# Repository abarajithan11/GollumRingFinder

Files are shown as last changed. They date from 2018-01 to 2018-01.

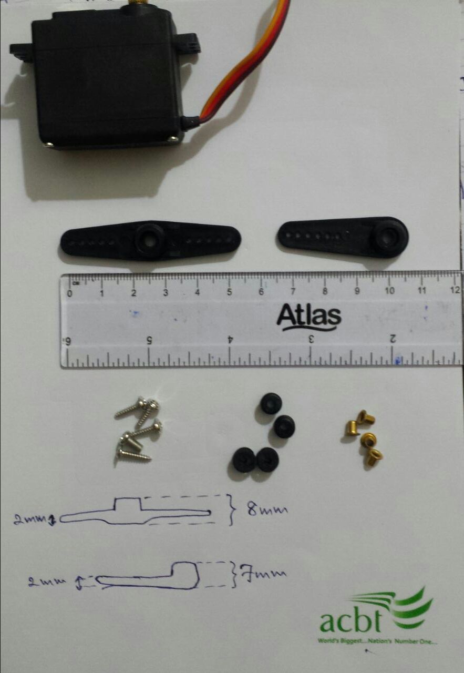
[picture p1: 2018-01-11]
Robot Arm/Arm/WhatsApp Image 2017-05-13 at 11.14.45 PM.jpeg

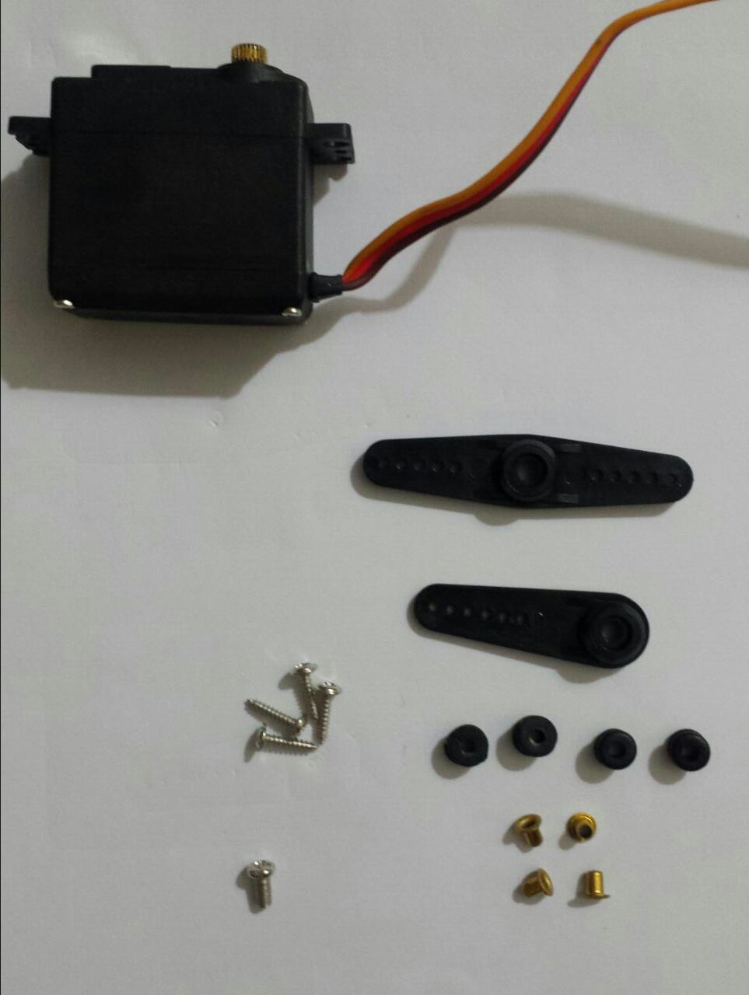
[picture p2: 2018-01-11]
Robot Arm/Arm/WhatsApp Image 2017-05-13 at 11.10.55 PM.jpeg

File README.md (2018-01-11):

# RingFinderRobot

This repository includes the code that was used to build Gollum, an outdoor mobile robot to perform GPS following, obstacle avoiding, wall following, color detection, parallel alignment and robotic arm manipulation.

# Task:

The robot starts from within the starting circle of 1m in radius. Out of three pre-defined target locations, one location is chosen at random and give to us in the start. We input the target location using a keypad/set of 3 switches. The robot should the follow GPS and visit the target, which is 20m away. On the way, there is a "forest" of obstracles (30 cm cubes) which the robot should avoid. Target is marked by a circle of white line (3cm thickness) 2m in radius around the target point.

At the target point, lies a cylindar, 50cm in radius. The cyclindar has 40 cm wide entrance on one side.The robot should find the cylindar, move to meet it, follow the wall around it, find the entrance, move in. Inside the cylindar lies a 5 cm high, 40cm diameter plate that contains a metal ring og 6cm diameter anywhere in it. The robot should be able to search and pick up the ring with an arm.

Then then robot should return to the starting location and stop.

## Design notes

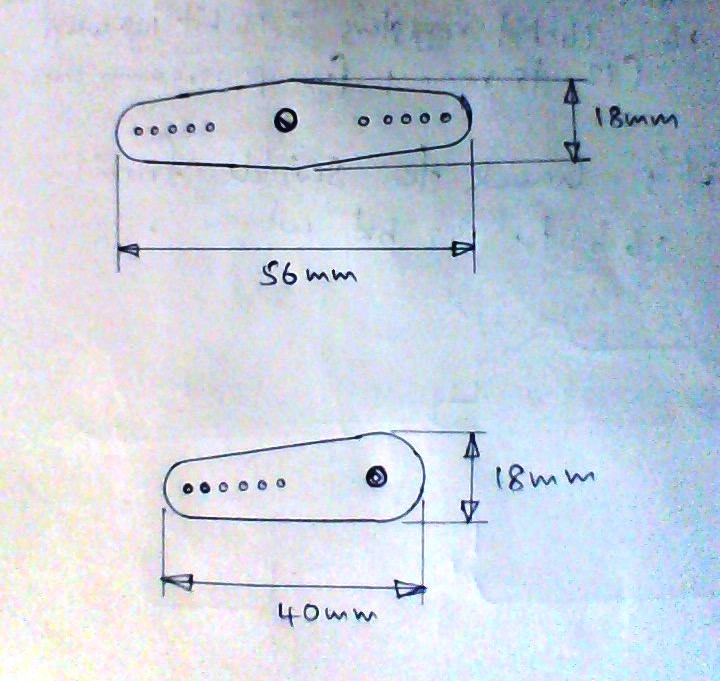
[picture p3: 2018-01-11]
Robot Arm/Arm/WIN_20170513_22_51_47_Pro.jpg

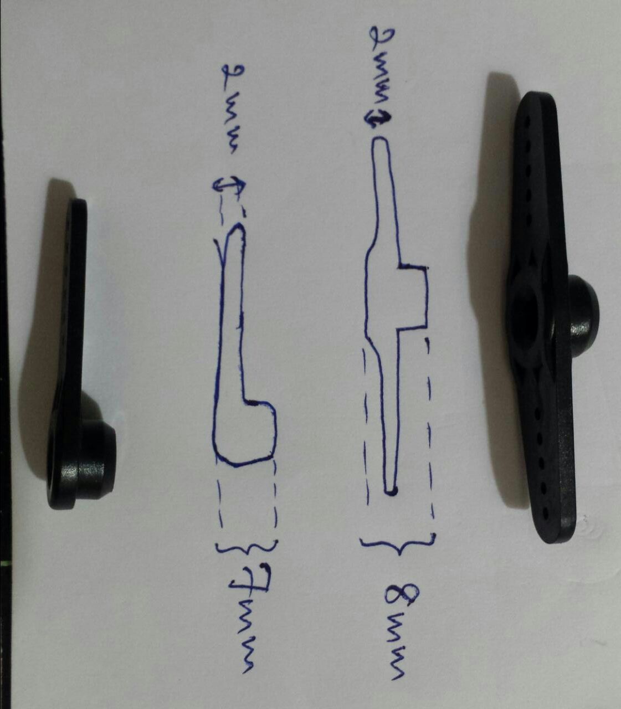
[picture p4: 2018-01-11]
Robot Arm/Arm/WhatsApp Image 2017-05-13 at 11.12.58 PM.jpeg

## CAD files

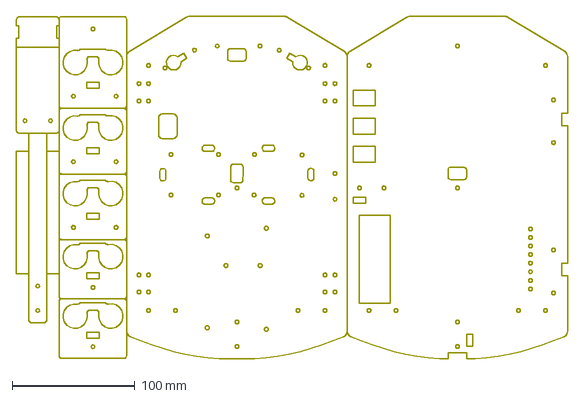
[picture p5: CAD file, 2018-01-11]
Laser Cut/Chassis 3.0.dxf
450.0 x 279.5 mm

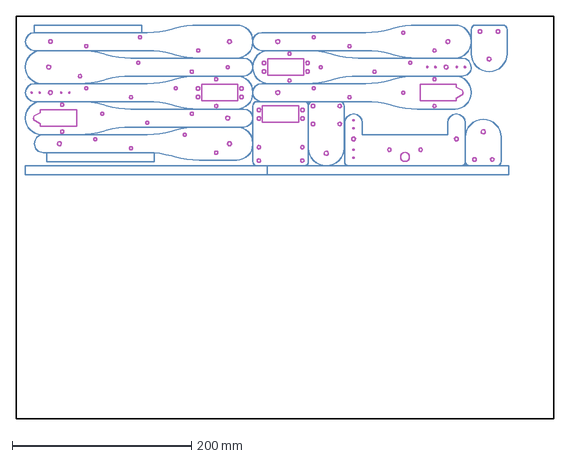
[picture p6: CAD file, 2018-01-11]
Robot Arm/Arm/Robot Arm.dxf
600.0 x 450.0 mm

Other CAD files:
Robot Arm/Robot Arm.dwg
Robot Arm/Arm/Final Laser.dwg
Robot Arm/Arm/Laser Cut arm_recover.dwg
Robot Arm/Arm/Laser Cut arm 2.0.dwg
Robot Arm/Arm/Chassis.dwg
Robot Arm/Arm/Laser Cut arm.dwg
Robot Arm/Arm/MG945Servo (1).dwg
Laser Cut/Chassis 3.0.dwg

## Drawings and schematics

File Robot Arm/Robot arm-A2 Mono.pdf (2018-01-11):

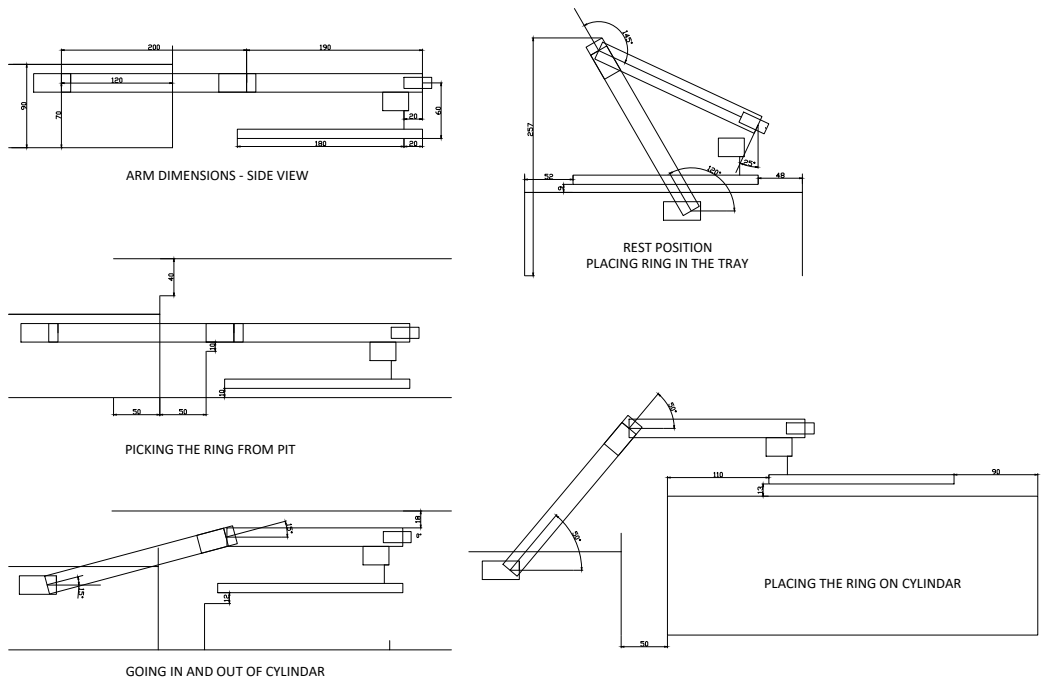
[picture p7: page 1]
ARM DIMENSIONS - SIDE VIEW PICKING THE RING FROM PIT GOING IN AND OUT OF CYLINDAR; REST POSITION PLACING RING IN THE TRAY PLACING THE RING ON CYLINDAR

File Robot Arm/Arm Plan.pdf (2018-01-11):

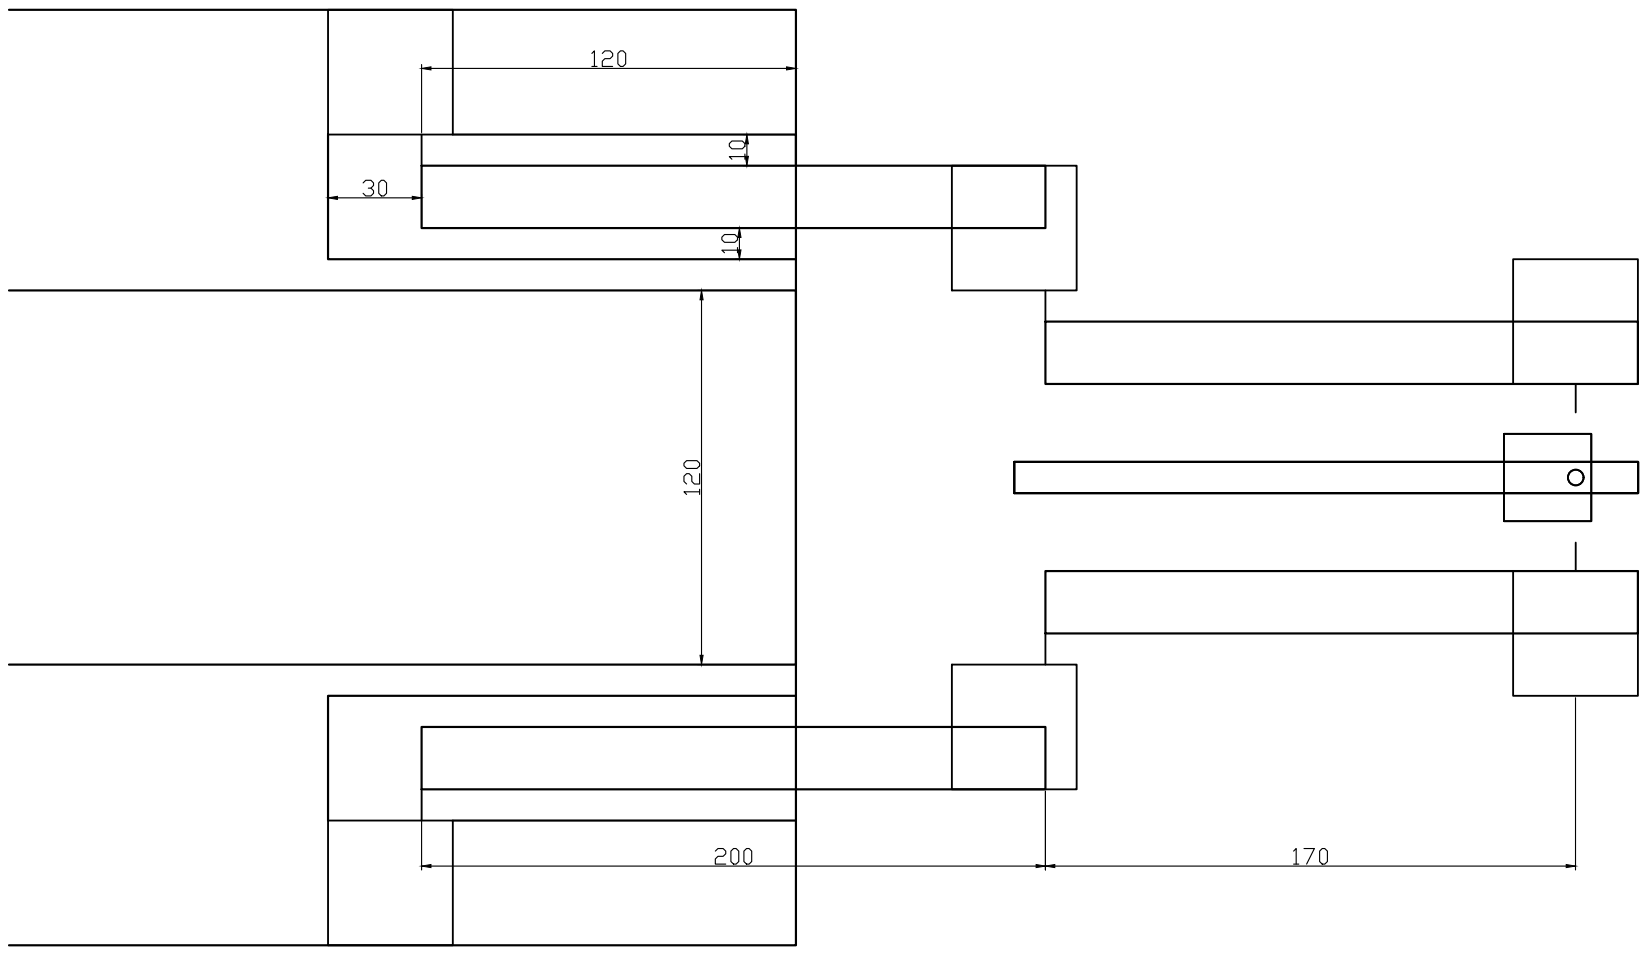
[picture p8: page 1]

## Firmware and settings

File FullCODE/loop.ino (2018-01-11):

void loop()
{  
  long timeCount = millis();
  
  if(taskStatus ==0)    //Starting
  {
    startCalibrate();
    selectLocation();
  }

  if(taskStatus == 1)   //Go to the target location
  {
    obsAvoid2();
    if(!(timeCount % 10000))
    {
      gotoGPS();
    }
    detectLine();
  }

  if(taskStatus ==2) //Found the boundary of target location, Display
  {
    lineFound();
  }
  if(taskStatus ==3) //Found the boundary, align perpendicular to it
  {
    lineAlign();
  }
  if(taskStatus ==4) //Print Aligned
  {
    lineAligned();
  }
  if(taskStatus ==5) //Now Rotate and search for cylindar
  {
    rotateSearch();
  }
  if(taskStatus ==6) //Cylindar found. Move towards it
  {
    wallMeet3();
  }
  if(taskStatus ==7) //Met the cylindar wall. Turn to become parallel to the wall
  {
    passToParallel();
  }
  if(taskStatus ==8) //Follow the wall
  {
    wallFollow();
  }
  if(taskStatus ==9) //Entrance found
  {
    turnInside();
  }
  if(taskStatus ==10) //Move inside
  {
    moveInside();
  }
  if(taskStatus ==11) //Pickup the ring
  {
    pickUpRing();
  }
  if(taskStatus ==12) //Moving outside
  {
    moveOutside();
    latTarget = startLat;
    longTarget = startLong;
  }
  if(taskStatus ==13) //Go to the Starting point
  {
    obsAvoid2();
    if(!(timeCount % 10000))
    {
      gotoGPS();
    }
  }
  if(taskStatus ==14) //Task over. Stop and Beep
  {
    motorBreak();
    while(1)
    {
      beep();
    }
  }

}

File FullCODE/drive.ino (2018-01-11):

#define fLTune 0.83
#define bLTune 1
#define rRTune 1

void drive(int motor_speed)
{
  motorSpeed('l', motor_speed);
  motorSpeed('r', motor_speed);
}

void motorSpeed(char side, int motor_speed) 
{
  int newSpeed;
  if (side == 'l') 
  {
    newSpeed = fLTune*motor_speed;
    if(newSpeed >255) newSpeed = 255;
    if (motor_speed > 0) 
    {
      digitalWrite(linB1, LOW);   digitalWrite(linB2, LOW);
      digitalWrite(linF1, HIGH);    digitalWrite(linF2, HIGH);
      analogWrite(lEn1, newSpeed); analogWrite(lEn2, newSpeed);
    }
    else 
    {
      digitalWrite(linB1, HIGH);    digitalWrite(linB2, HIGH);
      digitalWrite(linF1, LOW);   digitalWrite(linF2, LOW);
      analogWrite(lEn1, -newSpeed);analogWrite(lEn2, -newSpeed);
    }
  }
  else 
  {
    if (motor_speed > 0) 
    {
      digitalWrite(rinF1, HIGH);    digitalWrite(rinF2, HIGH);
      digitalWrite(rinB1, LOW);   digitalWrite(rinB2, LOW);
      analogWrite(rEn1, motor_speed); analogWrite(rEn2, motor_speed);
    }
    else {
      digitalWrite(rinF1, LOW);   digitalWrite(rinF2, LOW);
      digitalWrite(rinB1, HIGH);    digitalWrite(rinB2, HIGH);
      analogWrite(rEn1, -motor_speed);  analogWrite(rEn2, -motor_speed);
    }
  }
}




void motorBreak() 
{
  digitalWrite(rinF1, HIGH);
  digitalWrite(rinB1, HIGH);
  analogWrite(rEn1, 0);
  digitalWrite(linB1, HIGH);
  digitalWrite(linF1, HIGH);
  analogWrite(lEn1, 0);

  digitalWrite(rinF2, HIGH);
  digitalWrite(rinB2, HIGH);
  analogWrite(rEn2, 0);
  digitalWrite(linB2, HIGH);
  digitalWrite(linF2, HIGH);
  analogWrite(lEn2, 0);
}

void motorRevBreak() 
{
    highBreak();
    motorSpeed('l', -150);
    motorSpeed('r', -150);
    delay(70);
    highBreak();

}

void highBreak()
{
  digitalWrite(rinF1, HIGH);
  digitalWrite(rinB1, HIGH);
  analogWrite(rEn1, 200);
  digitalWrite(linB1, HIGH);
  digitalWrite(linF1, HIGH);
  analogWrite(lEn1, 200);

  digitalWrite(rinF2, HIGH);
  digitalWrite(rinB2, HIGH);
  analogWrite(rEn2, 200);
  digitalWrite(linB2, HIGH);
  digitalWrite(linF2, HIGH);
  analogWrite(lEn2, 200);
}

void rotate(int motor_speed)      //Positve -> anticlockwise
{
  motorSpeed('r', rRTune*motor_speed);
  motorSpeed('l', -motor_speed);
}
